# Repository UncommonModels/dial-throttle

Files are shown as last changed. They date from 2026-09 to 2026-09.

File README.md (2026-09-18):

# Dial Throttle (M5Stack Dial + SparkFun Qwiic Numpad)



This project turns an `M5Stack Dial` into a handheld model railroad throttle. It talks to JMRI
over WiThrottle, or joins an LCC network directly, with a `SparkFun Qwiic Keypad/Numpad
(COM-15290)` for function, turnout and loco-select keys.

**Documentation: <https://ngpaladi.github.io/dial-throttle/>**

| Idle, no loco | Half-step between notches | Ramping to notch 5 | Full speed |
| --- | --- | --- | --- |
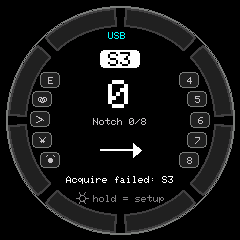
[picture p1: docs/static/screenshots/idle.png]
idle
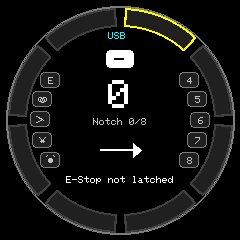
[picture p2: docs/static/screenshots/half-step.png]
half step
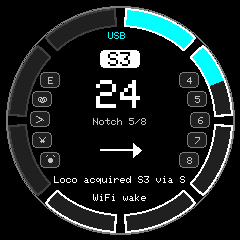
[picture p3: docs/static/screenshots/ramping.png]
ramping
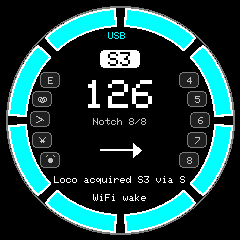
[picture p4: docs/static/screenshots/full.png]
full
|  |  |  |  |

| Reverse | E-Stop latched | Battery gauge | Settings menu |
| --- | --- | --- | --- |
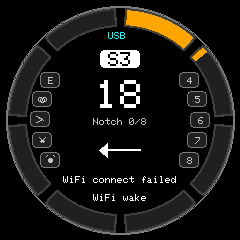
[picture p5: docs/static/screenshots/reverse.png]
reverse
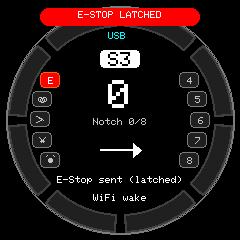
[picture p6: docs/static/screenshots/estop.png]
estop
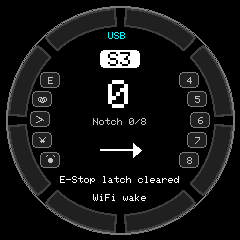
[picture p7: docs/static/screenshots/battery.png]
battery
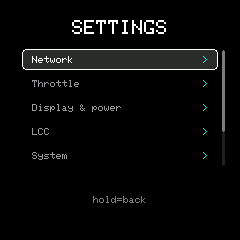
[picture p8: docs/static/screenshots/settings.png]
settings
|  |  |  |  |

## Features

- Notched throttle with momentum on the dial: 4, 8, 12 or 16 notches over speed steps `0..126`.
- Touchscreen brake, dial-button stop and direction change, and a latched emergency stop.
- WiThrottle for JMRI, or LCC / OpenLCB over GridConnect as a real node.
- Keypad functions, turnouts and loco selection, plus RFID loco selection with an optional
  MySQL lookup.
- WiFi, server and throttle settings stored in flash and editable on the device.
- Idle power saving for battery use that never cuts the link while the train is moving.

## Parts

| Qty | Part | Description |
| --- | --- | --- |
| 1 | `K130-V11` | M5Stack Dial |
| 1 | `15290` | SparkFun Qwiic Keypad, 12 button |
| 1 | `15109` | Qwiic to I2C Grove cable, 150 mm |
| 1 | `LION-1865-34` | 18650 Li-ion cell, 3.7 V 3.4 Ah |
| 1 | `BH-18650-PC` | 18650 holder, PC pin |
| 1 | `3922` | Molex Pico Blade 2-pin cable |
| 1 | `FE-USB2CC-PM-6IN` | Panel-mount USB-C cable, 6 in |

`parts/partslist.csv` has the Digi-Key numbers, and the
[Parts page](https://ngpaladi.github.io/dial-throttle/docs/parts/) explains what each item is for
and what the optional additions are.

## Quick start

With [arduino-cli](https://arduino.github.io/arduino-cli/) and `make`:

```bash
make flash PORT=/dev/ttyACM0   # build and upload; the first build downloads the ESP32 core
make monitor                   # serial console at 115200 baud
make help                      # every target
```

Or run the guided installer, which fetches arduino-cli for you: `./install.sh` on Linux and
macOS, `.\install.ps1` or `install.bat` on Windows.

To use the Arduino IDE, open `DialThrottle/DialThrottle.ino` and follow the board settings in
[Getting started](https://ngpaladi.github.io/dial-throttle/getting-started/#build-with-the-arduino-ide).

A unit with nothing saved opens its settings menu on first boot, so WiFi and the server can be
set on the device. Compile-time defaults are in `DialThrottle/config.h`.

## Repository layout

| Path | Contents |
| --- | --- |
| `DialThrottle/` | Arduino sketch: firmware, `config.h`, and `sketch.yaml` with pinned versions |
| `Makefile` | Build, flash, monitor and docs targets |
| `install.py` | Guided installer (`install.sh`, `install.ps1` and `install.bat` wrap it) |
| `docs/` | Hugo documentation site |
| `parts/partslist.csv` | Parts list, rendered on the site's Parts page |
| `tools/screenshot.py` | Captures the screen over serial |
| `case/` | Printable case |
| `rfid_mysql_schema.sql` | Sample table for RFID lookups |

## Documentation site

The site in `docs/` is built with [Hugo](https://gohugo.io/) and published to GitHub Pages by
`.github/workflows/pages.yml` on every push that touches `docs/` or `parts/`.

```bash
make serve                     # dev server with live reload on :1313
make docs                      # build into docs/public
```

The Parts page is generated from `parts/partslist.csv`, so editing that CSV updates the
documentation. `make site-assets` restages it, and `make docs` and `make serve` do that for you.

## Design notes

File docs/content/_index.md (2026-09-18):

---
title: "Dial Throttle"
---
| Idle, no loco | Half-step between notches | Ramping to notch 5 | Full speed |
| --- | --- | --- | --- |
| {{< shot idle.png "idle" >}} | {{< shot half-step.png "half step" >}} | {{< shot ramping.png "ramping" >}} | {{< shot full.png "full" >}} |

| Reverse | E-Stop latched | Battery gauge | Settings menu |
| --- | --- | --- | --- |
| {{< shot reverse.png "reverse" >}} | {{< shot estop.png "estop" >}} | {{< shot battery.png "battery" >}} | {{< shot settings.png "settings" >}} |

## What it does

- Connects to your WiFi network and to a JMRI WiThrottle server (default port `12090`), or to an
  LCC GridConnect server as a real OpenLCB node.
- Uses the dial as a notched throttle with momentum. You choose 4, 8, 12 or 16 notches, and speed
  runs over steps `0..126`.
- Caps reverse at half the notches by default, so the dial only reaches half speed backwards.
- Brakes while you hold the touchscreen. A press of the dial button stops the loco, or reverses it
  when already stopped.
- Adds function, turnout and loco-select keys through a SparkFun Qwiic keypad.
- Selects a loco by RFID tag, looked up in a MySQL table, a local map, or the tag UID itself.
- Saves power on battery by dimming, turning the display off, suspending WiFi and finally
  powering off, but never while the train is moving.
- Keeps WiFi, server and throttle settings in flash, editable on the device.

## Where to go next

| Page | Covers |
| --- | --- |
| [Getting started]({{< relref "docs/getting-started" >}}) | Hardware, wiring, building and flashing |
| [Parts list]({{< relref "docs/parts" >}}) | What to order, with Digi-Key numbers |
| [Using the throttle]({{< relref "docs/using" >}}) | Dial controls, keypad, settings menu |
| [Protocols]({{< relref "docs/protocols" >}}) | WiThrottle and LCC details |
| [Power and battery]({{< relref "docs/power" >}}) | Idle tiers, battery gauge and charge detection |
| [RFID]({{< relref "docs/rfid" >}}) | Tag lookup and the MySQL table |
| [Serial console]({{< relref "docs/serial" >}}) | Debug commands and screenshots |
| [Troubleshooting]({{< relref "docs/troubleshooting" >}}) | JMRI setup and common problems |

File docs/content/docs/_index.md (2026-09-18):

---
title: "Documentation"
---

Building, configuring and operating the Dial Throttle.

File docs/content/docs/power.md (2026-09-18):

---
title: "Power and battery"
description: "Idle power saving, the battery gauge and charge detection."
weight: 5
---

## Idle tiers

The firmware saves power in stages as the throttle sits idle.

| Tier | After | What happens |
| --- | --- | --- |
| Active | Any input | Backlight at full brightness, WiFi in minimum modem sleep |
| Dim | Dim delay | Backlight dimmed, WiFi in maximum modem sleep, RFID and keypad polled less often |
| Display off | Display-off delay | Backlight off and the LCD panel asleep. Once the loco is stopped, WiFi turns off and the ESP32 light-sleeps between polls |
| Power off | Power-off minutes, loco stopped | The loco is released, the session closed, and the unit powers down |

Any input returns to the active tier: the dial, touch, the button, the keypad, an RFID tag or a
serial command. During light sleep the unit wakes on dial rotation, the dial button, a screen
touch, or every `LIGHT_SLEEP_INTERVAL_MS`.

After a power off on battery, press the dial button to turn the unit back on. On USB power it
deep-sleeps instead, and a screen touch reboots it. The backlight pin is held low through deep
sleep, so the screen stays dark.

> WiFi is never suspended, and the unit never light-sleeps or powers off, while the loco is
> moving or braking. A train running hands-off keeps receiving heartbeats.

### Other savings

- The RFID reader's 13.56 MHz field is only on for a few milliseconds per poll
  (`RFID_POLL_ACTIVE_MS`, `RFID_POLL_IDLE_MS`).
- The keypad is polled on a schedule (`KEYPAD_POLL_ACTIVE_MS`, `KEYPAD_POLL_IDLE_MS`). It buffers
  presses in its own FIFO between polls.
- WiFi reconnects don't block, and WiThrottle reconnects are retried every 5 seconds.

### USB serial and light sleep

USB serial drops during light sleep. By default light sleep is skipped while a computer is
attached (`LIGHT_SLEEP_SKIP_WHEN_USB_SERIAL`). It still happens on battery or a plain USB
charger. If you plug a light-sleeping unit into a computer and the port doesn't appear, touch the
screen or turn the dial first; it stays awake while the computer is attached.

### Tuning

Brightness, delays and the power-off time are in the settings menu. The rest are in `config.h`:

- `ENABLE_WIFI_MODEM_SLEEP`, `ENABLE_WIFI_MAX_MODEM_SLEEP_WHEN_IDLE`
- `ENABLE_WIFI_POWER_GATING_WHEN_DISPLAY_OFF`
- `ENABLE_DISPLAY_PANEL_SLEEP`
- `ENABLE_LIGHT_SLEEP_WHEN_DISPLAY_OFF`, `LIGHT_SLEEP_INTERVAL_MS`, `LIGHT_SLEEP_SKIP_WHEN_USB_SERIAL`
- `ENABLE_RFID_ANTENNA_DUTY_CYCLE`, `RFID_POLL_ACTIVE_MS`, `RFID_POLL_IDLE_MS`
- `KEYPAD_POLL_ACTIVE_MS`, `KEYPAD_POLL_IDLE_MS`
- `UI_MIN_REDRAW_INTERVAL_MS`, which merges bursts of changes into one frame
- `CPU_FREQ_MHZ`, 240 by default. A full redraw takes about 17 ms of CPU at 240 MHz and about
  104 ms at 80 MHz. Inputs are polled between frames, so a slow redraw makes the dial feel laggy.
  Drop to 80 only if you'd rather have the battery life than the responsiveness.

## Battery gauge

| Battery gauge | Low battery |
| --- | --- |
| {{< shot battery.png "battery" >}} | {{< shot battery-low.png "low" >}} |

The Dial has a 1.25 mm 2-pin battery connector and a charger, but no battery voltage sense line,
so a stock unit cannot read its battery. To show the battery level, add a resistor divider from
the battery to an ADC1 pin on Port B:

```
BAT+ ---[ R1 100k ]---+--- GPIO1 (or GPIO2, Port B)
                      |
                   [ R2 100k ]
                      |
                     GND
```

Then in `config.h` set `BATTERY_ADC_PIN` to `1` (or `2`) and `BATTERY_DIVIDER_RATIO` to
`(R1 + R2) / R2`, which is 2.0 for 100k/100k.

A battery icon with the percentage appears at the top of the screen. It turns yellow below 40%
and red at or below `BATTERY_LOW_WARN_PERCENT`, with a one-time low-battery beep. Set
`BATTERY_SHOW_VOLTAGE` to `true` to show millivolts while calibrating the ratio. With
`BATTERY_ADC_PIN = -1` the indicator is hidden.

## Charging and power source

According to the Dial schematic, the TP4057 charger's `CHRG` and `STDBY` pins aren't wired to the
ESP32, and the Grove 5V pin is boosted from the battery. A stock unit can't tell whether it is
charging.

Without extra hardware it can only detect a USB *host*, meaning a computer sending USB frames. A
plain USB charger or the DC terminal looks the same as battery power. The indicator row above the
loco address shows:

| Label | Meaning | Needs |
| --- | --- | --- |
| `USB` | A computer is attached | Nothing |
| `PWR` | External power detected | `POWER_SENSE_ADC_PIN` |
| `CHG` | Charging | `CHARGE_STATUS_PIN` |

- **`POWER_SENSE_ADC_PIN`**: wire a 100k/100k divider from the 5V input rail (StampS3 header pin
  `M5V`, net `+5VIN`, only live on USB or DC-terminal power) to GPIO1 or GPIO2. Don't use the
  Grove 5V pin; it is powered on battery too.
- **`CHARGE_STATUS_PIN`**: solder a wire from the TP4057 `CHRG` pin (pin 1, open drain, low while
  charging) to a free GPIO: GPIO39, 43 or 44 on the StampS3 header, or GPIO1 or 2. The firmware
  enables the internal pull-up.

With `POWER_OFF_ONLY_ON_BATTERY` (on by default) the idle power-off is skipped whenever external
power is detected. On a stock unit that only covers a computer, so on a wall charger it still
powers off after the idle time. The `bat` serial command prints the detected source and charge
state.

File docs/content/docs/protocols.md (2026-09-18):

---
title: "Protocols"
description: "WiThrottle for JMRI, or LCC/OpenLCB over GridConnect."
weight: 4
---

The throttle speaks one of two protocols. Choose it on the device under **Network**, or set the
default for an unconfigured unit with `THROTTLE_PROTOCOL_DEFAULT` in `config.h`.

## WiThrottle

WiThrottle is the default. The implementation was checked against the JMRI WiThrottle protocol
specification and JMRI's own server code.

### Commands sent

| Command | Purpose |
| --- | --- |
| `N` | Client name |
| `HU` | Unique client ID |
| `*+`, then `*` every 2 seconds | Heartbeat |
| `M0+` | Acquire the loco |
| `M0A...<;>V` | Speed |
| `M0A...<;>R` | Direction |
| `M0A...<;>f` | Set a function's state |
| `M0A...<;>X` | Emergency stop |

Functions use the force-function form, which sets a function's state directly instead of
emulating a key press. It needs WiThrottle protocol 2.0 or later.

### Messages handled

The receive path handles the version line, alerts and info messages, acquire confirmations,
steal prompts, releases, and property notifications for speed, direction and function state.
Reports for other locomotives on the throttle are ignored.

A negative speed from the server means the command station has the address in emergency stop.
That latches the throttle's own E-Stop, so momentum cannot ramp the train back up.

### Acquiring

Acquiring is confirmed, not assumed. If the server doesn't answer, the request is retried up to
`ACQUIRE_MAX_ATTEMPTS` times. If another throttle holds the loco, the server asks whether to
steal it. `WITHROTTLE_AUTO_STEAL` decides whether that happens automatically or waits for the
`steal` serial command.

Once the loco is confirmed, the throttle pushes its current direction, speed and function states
to the server. That is what restores the train after a reconnect.

## LCC / OpenLCB over GridConnect

Choose **LCC** under **Network** in the settings menu, or build with:

```bash
make flash DEFINES=-DTHROTTLE_PROTOCOL_DEFAULT=PROTOCOL_LCC_GRIDCONNECT
```

The throttle opens a GridConnect TCP connection to the configured server, either JMRI's LCC
GridConnect server or a CAN gateway, and joins the network as a real node:

- Allocates a CAN alias with the standard CID, RID and AMD sequence, and reclaims on a conflict.
- Announces itself with Initialization Complete, and answers Verify Node ID and Alias Map
  Enquiry.
- Finds the locomotive by its well-known DCC train node ID, `06.01.00.00.xx.xx`, where long
  addresses set the top two bits. Short address 3 is `06.01.00.00.00.03`; long address 341 is
  `06.01.00.00.C1.55`.
- Assigns itself as that train's controller, then sends speed, functions and emergency stop with
  the traction protocol. Speed is an IEEE half-precision value in metres per second whose sign
  carries direction, so reverse at a standstill is negative zero.

### Node ID

Set `LCC_NODE_ID` for this throttle. The default keeps the `05.01.01` prefix, which openlcb.org
set aside for non-commercial use, and fills the low three bytes from the board's MAC address, so
each unit is unique.

### Check against your layout

- **Speed scale.** `LCC_FULL_SPEED_MPH` maps the top notch onto a prototype speed. The default of
  126 makes one speed step one mph, which matches the usual OpenMRN command station mapping.
- **Turnouts.** LCC has no address-based turnout command, so turnout `n` produces event
  `LCC_TURNOUT_EVENT_BASE + 2n` or `+ 2n + 1`. That is a convention, not a standard.

## Testing without a layout

Build with serial-only output to inspect either protocol:

```bash
make flash DEFINES=-DSERIAL_OUTPUT_ONLY_DEFAULT=1
```

Every frame the throttle would send is printed to the console instead. The serial commands
`wtin <line>` and `lccin <frame>` feed in messages as if a server had sent them, and `lcc` prints
the node ID, alias and controller state.

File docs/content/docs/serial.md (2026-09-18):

---
title: "Serial console"
description: "Debug commands and screen captures over USB."
weight: 7
---

The throttle takes commands over USB serial at 115200 baud. Type a command and press Enter.

```bash
make monitor                   # or: make monitor PORT=/dev/ttyACM1
```

## Throttle and loco

| Command | Action |
| --- | --- |
| `status` | Print WiFi, server and loco state |
| `acq` | Acquire the configured loco |
| `rel` | Release the loco |
| `loco <addr> <s/l>` | Set the active loco, short or long, and acquire it |
| `steal` | Take a loco another throttle holds |
| `speed <0-126>` | Set the speed step |
| `notch <n>` | Set the throttle notch, from 0 to the notch count |
| `dir <f/r/t>` | Forward, reverse or toggle |
| `fn <0-28> <on/off/t>` | Function on, off or toggle |
| `estop` | Emergency stop |
| `clear` | Clear the E-Stop latch (`estop clear` also works) |

## Connection

| Command | Action |
| --- | --- |
| `wifi` | Reconnect WiFi |
| `wt` | Reconnect to the server |
| `send <raw>` | Send a raw WiThrottle line, e.g. `send M0A*<;>qV` |
| `lcc` | LCC node ID, alias and controller state |

## Settings

| Command | Action |
| --- | --- |
| `settings` | Print the settings and open the settings menu |
| `set ssid <name>` | Set and save the WiFi name |
| `set pass <password>` | Set and save the WiFi password |
| `set ip <a.b.c.d>` | Set and save the server address |
| `set port <n>` | Set and save the server port |
| `set proto <wt/lcc>` | Choose WiThrottle or LCC GridConnect |
| `defaults` | Reset every setting to the `config.h` defaults |

## Power and diagnostics

| Command | Action |
| --- | --- |
| `diag` | Idle timer, last input source, encoder count, notch and pending half-step, redraw and loop timing. Doesn't reset the idle timer |
| `bat` | Battery reading, power source and charge state |
| `tier <0/1/2>` | Force a backlight tier. `tier 2` checks that the screen really goes dark |
| `off` | Power off now |
| `help` | List every command |

## Testing

| Command | Action |
| --- | --- |
| `enc <counts>` | Inject raw encoder counts, 2 per detent |
| `btn [long]` | Fake a dial button press, or a long press |
| `simbat <pct/-1>` | Fake a battery percentage; `-1` clears it |
| `wtin <line>` | Inject a line as if the WiThrottle server sent it |
| `lccin <frame>` | Inject a GridConnect frame |
| `shot` | Dump the screen as hex |

To see what the throttle would send without a layout, build with
`make flash DEFINES=-DSERIAL_OUTPUT_ONLY_DEFAULT=1`. Outgoing WiThrottle lines are printed as
`WT> ...` instead of being transmitted.

## Screenshots

`tools/screenshot.py` sends `shot`, decodes the frame and writes a PNG. It needs `pyserial` and
`Pillow`. Every screenshot on this site was captured this way.

```bash
make screenshot PORT=/dev/ttyACM0
python3 tools/screenshot.py --setup "notch 5" --settle 3 shot.png
```

`--setup` runs a serial command before the capture and can be repeated. `--settle` waits that many
seconds afterwards, which lets momentum ramp the speed up. Without Pillow the raw hex dump is saved
next to the output, and `--decode dump.hex out.png` converts it later.

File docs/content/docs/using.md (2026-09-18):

---
title: "Using the throttle"
description: "Dial controls, the keypad, and the on-device settings menu."
weight: 3
---

## Dial controls

The throttle works like a locomotive notch controller with momentum.

| Control | Action |
| --- | --- |
| Turn the dial | Select a throttle notch |
| Hold the touchscreen | Brake while held |
| Press the dial button, moving | Stop immediately: notch 0, speed 0 |
| Press the dial button, stopped | Reverse direction |
| Press the dial button, E-Stop latched | Clear the latch |
| Hold the dial button about a second | Open the settings menu |

### Notches

Two detents in the same direction move one notch, like a gated notch lever: one detent up then
one back down returns to the notch and changes nothing. A half-step shows as a yellow outline on
the block being moved into, and is held until you complete or undo it. The detents per notch can
be changed in the settings menu.

| Half-step | 4 notches | 16 notches |
| --- | --- | --- |
| {{< shot half-step.png "half step" >}} | {{< shot notches-4.png "4 notches" >}} | {{< shot notches-16.png "16 notches" >}} |

A block is outlined white when its notch is selected, and fills with the direction color as the
actual speed reaches it. The big number is the real speed step (`0..126`) and the small line
under it is the notch. The address shows `-` until a loco is selected.

Reverse is capped at half the notches, so the dial only reaches half speed backwards. Set
`REVERSE_NOTCH_DIVISOR` in `config.h` to 1 to give reverse the full range.

### Momentum and braking

Actual speed ramps toward the selected notch at `MOMENTUM_ACCEL_STEPS_PER_SEC` (default 8 per
second, about 16 seconds from stop to full) and coasts down at `MOMENTUM_DECEL_STEPS_PER_SEC`
(default 5 per second). Both rates can be changed in the settings menu, and momentum can be
turned off there for direct notch-to-speed control.

Holding the touchscreen brakes hard. On release the ramp resumes toward the selected notch.
Braking to a full stop drops the notch to 0.

### Encoder decoding

The raw encoder count must move a full detent before anything is accepted, so contact chatter
never registers. A reversal within `ENCODER_REVERSAL_PAUSE_MS` of a detent is treated as a decoder
miscount and absorbed. A deliberate turn-back after a pause registers immediately.

## Keypad

With a SparkFun Qwiic keypad attached:

| Key | Action |
| --- | --- |
| `0` to `8` | Toggle function `F0` to `F8` |
| `9` | Emergency stop |
| `*` | Turnout mode: enter digits, press `*` again to flip |
| `#` | Loco select mode: enter digits, press `#` again to acquire |

Selecting a new loco releases the old one and acquires the new one. Speed, direction, function
and E-Stop actions acquire the loco first if needed.

## Settings menu

Hold the dial button for about a second to open the menu. The home screen shows
`Btn Hold = Setup` as a reminder. The menu only opens with the train stopped.

| Menu | Throttle page | Server address | Text entry |
| --- | --- | --- | --- |
| {{< shot settings.png "settings" >}} | {{< shot settings-throttle.png "throttle page" >}} | {{< shot settings-ip.png "ip" >}} | {{< shot settings-text.png "text entry" >}} |

Turn the dial to move or to change a value, press to activate or to step to the next field, and
hold to go back. On the keypad, digits type straight into the field, `#` acts as a press and `*`
as a hold.

| Page | Settings |
| --- | --- |
| Network | WiFi name and password, protocol (WiThrottle or LCC), server address, port |
| Throttle | Default loco address and type, notches (4, 8, 12, 16), detents per notch, reverse dial direction, momentum, acceleration and deceleration |
| Display & power | Active and dim brightness, dim and display-off delays, power-off minutes (0 means never), sound |
| System | RFID reader on or off, reset to defaults |

Switching protocol moves the port to that protocol's usual default. The server address is edited
octet by octet. Text fields use a character picker: turn to a character and press to add it, `<X`
backspaces, and `OK` or a hold finishes. The password is shown masked.

Choose **Save & exit** to write the settings and reconnect, or **Discard & exit** to reload what
was last saved. Settings are stored in flash as one versioned record and survive a reflash.
Firmware whose settings layout has changed falls back to defaults rather than loading a
mismatched record.

The same values can be set over the [serial console]({{< relref "docs/serial" >}}).

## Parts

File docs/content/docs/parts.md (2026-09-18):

---
title: "Parts list"
description: "Everything needed to build one throttle."
weight: 2
---

One throttle, as built. Every line is stocked at Digi-Key, and the quantities are per unit.

{{< parts >}}

## What each part is for

- **M5Dial** is the whole throttle: an ESP32-S3, a round 240×240 touchscreen, a rotary encoder
  with a push button, an RFID reader and a speaker in one enclosure.
- **Qwiic keypad and cable** add the function, turnout and loco-select keys. The throttle works
  without them, and picks one up whenever it is plugged in.
- **18650 cell, holder and Pico Blade cable** make it cordless. The Dial charges the cell over
  USB-C. The cable matches the Dial's 1.25 mm 2-pin battery connector, so check the polarity
  against the case before the first connection.
- **Panel-mount USB-C cable** brings the Dial's USB port out to the edge of the case, for
  charging and reflashing without opening it.

A printable case is in `case/` in the repository, as an STL with the FreeCAD source beside it. It is designed so all parts mount with  M2 screws without threaded inserts.

## Optional extras

None of these are in the list above; all are described elsewhere in these docs.

| Add | For | See |
| --- | --- | --- |
| Two 100 kΩ resistors | Battery voltage divider, which the gauge needs | [Battery gauge]({{< relref "docs/power#battery-gauge" >}}) |
| Two more 100 kΩ resistors | Sensing external power on the 5 V input rail | [Charging and power source]({{< relref "docs/power#charging-and-power-source" >}}) |
| One wire to the charger's `CHRG` pin | Showing charge state | [Charging and power source]({{< relref "docs/power#charging-and-power-source" >}}) |
| RFID tags, 13.56 MHz | Selecting a loco by tag | [RFID]({{< relref "docs/rfid" >}}) |

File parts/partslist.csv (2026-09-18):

Digikey Part Number | Manufacturer Part Number | Description | Quantity
2221-K130-V11-ND | K130-V11 | M5DIAL V1.1 | 1
1568-15290-ND | 15290 | QWIIC KEYPAD - 12 BUTTON | 1
1568-15109-ND | 15109 | QWIIC TO I2C GROVE CABLE 150MM | 1
3145-LION-1865-34-ND | LION-1865-34 | BATTERY LITH-ION 3.7V 3.4AH 1865 | 1
BH-18650-PC-ND | BH-18650-PC | BATTERY HOLDER 18650 PC PIN | 1
1528-2732-ND | 3922 | MOLEX PICO BLADE 2-PIN CABLE - 2 | 1
5600-FE-USB2CC-PM-6IN-ND | FE-USB2CC-PM-6IN | 6inch USB2-C to C Panel M/F | 1

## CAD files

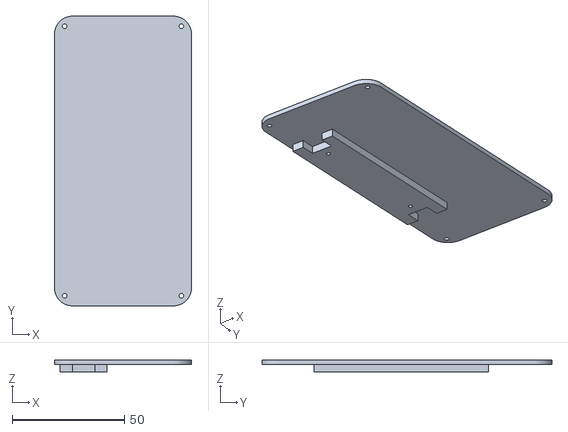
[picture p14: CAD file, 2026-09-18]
case/M5DialController-Backplate.stl
61.0 x 129.0 x 5.30

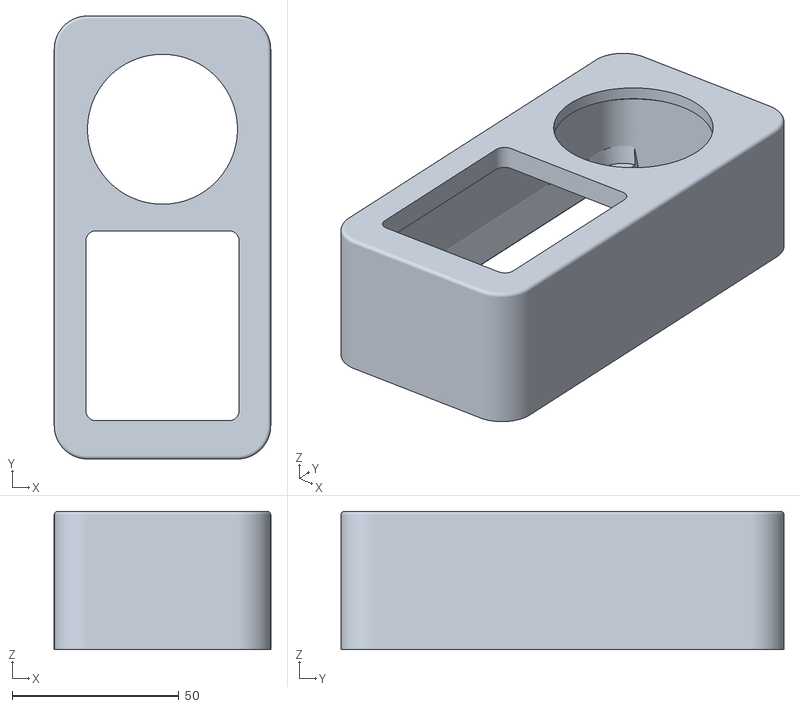
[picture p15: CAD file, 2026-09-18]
case/M5DialController-Body.stl
65.0 x 133.0 x 41.5

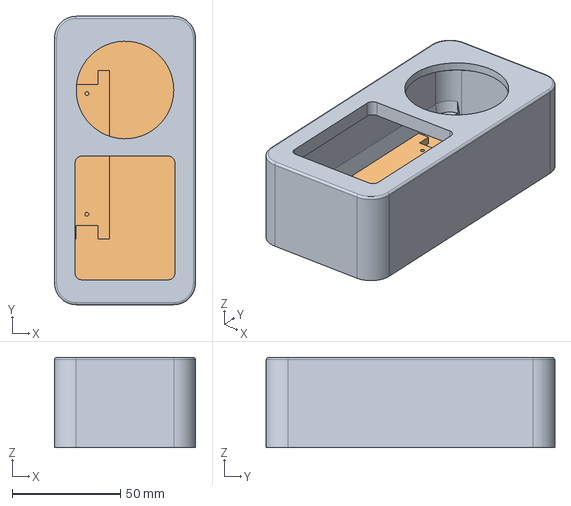
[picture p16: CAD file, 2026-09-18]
case/M5DialController.FCStd
65.0 x 133.0 x 41.5 mm
Backplate

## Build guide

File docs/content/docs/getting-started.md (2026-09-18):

---
title: "Getting started"
description: "Hardware, wiring, and building and flashing the firmware."
weight: 1
---

## Hardware

- M5Stack Dial (ESP32-S3)
- SparkFun Qwiic Keypad/Numpad (COM-15290), optional
- Qwiic cable

The [parts list]({{< relref "docs/parts" >}}) has the exact items, with Digi-Key numbers. A
printable case is in the repository under `case/` (`M5DialController.stl`, with the FreeCAD
source alongside).

## Wiring

The Qwiic connector carries `3V3`, `GND`, `SDA` and `SCL`. Plug the Qwiic cable into the Dial's
Grove port (Port A), or into an adapter that exposes `3V3/GND/SDA/SCL`.

The firmware expects the keypad at the SparkFun default I2C address, `0x4B`. A keypad plugged in
after boot is picked up within about 10 seconds.

### Battery
The M5Stack Dial has a Molex Picoblade 1.25mm pitch connector under the Stamp module on the bottom of the dial. The parts list suggests a preassembled cable to break this out into wire leads. **BE EXTREMELY CAREFUL ABOUT POLARITY**. The PCB should have an indicator of the positive terminal. This may not be the red cable in a red/black pair for an assembled cable. If you choose not to use the 18650 battery setup (which requires soldering of the leads to the battery holder), you likely can find a smaller battery and shrink the height of the case. However, this will likely require constructing a custom adapter cable.

## Project layout

| Path | Contents |
| --- | --- |
| `DialThrottle/` | The Arduino sketch. `setup()` and `loop()` are in `main.cpp` |
| `DialThrottle/config.h` | Compile-time defaults and hardware options |
| `DialThrottle/sketch.yaml` | Board options and pinned core and library versions |
| `Makefile` | Build, flash, monitor and docs targets |
| `install.py` | Guided installer for people who don't want to use a terminal much |
| `parts/partslist.csv` | The [parts list]({{< relref "docs/parts" >}}), rendered onto this site |
| `docs/` | This documentation site (Hugo) |
| `tools/screenshot.py` | Captures the screen over serial |
| `rfid_mysql_schema.sql` | Sample table for RFID lookups |

## Configure

WiFi, the server address, the protocol and the default loco can all be set on the device after
flashing (see [Using the throttle]({{< relref "docs/using#settings-menu" >}})). A unit with
nothing saved opens the settings menu on first boot.

To bake in defaults instead, edit `DialThrottle/config.h` before building:

- `WIFI_SSID`, `WIFI_PASS`
- `WITHROTTLE_HOST`, `WITHROTTLE_PORT`
- `LOCO_ADDRESS`, `LOCO_IS_LONG_ADDRESS`
- `THROTTLE_PROTOCOL_DEFAULT`, see [Protocols]({{< relref "docs/protocols" >}})

Settings saved on the device take priority over these values, and survive a reflash.

## Build and flash with make

You need [arduino-cli](https://arduino.github.io/arduino-cli/) and `make`. The board, the ESP32
core and every library are pinned in `DialThrottle/sketch.yaml`, so the first build downloads
what it needs. The ESP32 core alone is several hundred MB.

```bash
make build                     # compile
make flash                     # compile and upload to /dev/ttyACM0
make monitor                   # serial console at 115200 baud
make help                      # list every target
```

With more than one board attached, pass the port:

```bash
make flash PORT=/dev/serial/by-id/usb-Espressif_USB_JTAG_serial_debug_unit_<MAC>-if00
```

`DEFINES` adds preprocessor flags without editing `config.h`. Changing it forces a rebuild:

```bash
make flash DEFINES=-DTHROTTLE_PROTOCOL_DEFAULT=PROTOCOL_LCC_GRIDCONNECT
```

## Build with the Arduino IDE

1. Install the ESP32 boards package. Add
   `https://raw.githubusercontent.com/espressif/arduino-esp32/gh-pages/package_esp32_index.json`
   under **File > Preferences > Additional boards manager URLs**, then install **esp32** by
   Espressif, version 3.1.3, from the Boards Manager.
2. Install these libraries from the Library Manager: **M5Dial**, **M5Unified**, **M5GFX**,
   **SparkFun Qwiic Keypad Arduino Library** and **MySQL Connector Arduino**. Running
   `make deps` does both steps from a terminal, at the pinned versions.
3. Open `DialThrottle/DialThrottle.ino`.
4. Under **Tools**, choose board **M5Dial** and set:
   - USB CDC On Boot: **Enabled**
   - USB Mode: **Hardware CDC and JTAG**
   - Flash Size: **8MB (64Mb)**
   - Partition Scheme: **8M with spiffs (3MB APP/1.5MB SPIFFS)**
5. Select the port and click **Upload**.

> USB CDC On Boot must be enabled, or the serial console goes to pins that the Dial doesn't
> expose.

## Guided installer

For less technical users, the installer downloads arduino-cli if needed, offers to open
`config.h`, lets you pick the serial port, then builds and flashes.

| Platform | Command |
| --- | --- |
| Linux, macOS | `./install.sh` |
| Windows PowerShell | `.\install.ps1` |
| Windows Command Prompt | `install.bat` |

All three need Python 3. For unattended installs at clubs or events:

```bash
./install.sh --yes --port /dev/ttyACM0 --no-monitor
```

| Flag | Effect |
| --- | --- |
| `--yes`, `-y` | Accept defaults, never prompt |
| `--port <path>` | Use this port without asking |
| `--monitor`, `--no-monitor` | Open, or skip, the serial monitor after flashing |
| `--edit-config`, `--no-edit-config` | Open, or skip, the config editor |
| `--help` | Show all options |

## Serial permissions on Linux

If the board doesn't show up or the upload is refused, add yourself to the `dialout` group, then
log out and back in:

```bash
sudo usermod -aG dialout "$USER"
```

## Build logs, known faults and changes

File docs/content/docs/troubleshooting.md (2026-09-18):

---
title: "Troubleshooting"
description: "JMRI setup and the problems that come up most."
weight: 8
---

## JMRI setup

1. In JMRI, start the WiThrottle server.
2. Confirm the server port, `12090` by default.
3. Make sure the Dial and the JMRI computer are on the same network.
4. If a firewall is enabled, allow TCP port `12090`.

## Keypad not detected

- Check the Qwiic cable and the connector.
- Confirm the keypad address is `0x4B`, the SparkFun default.
- The status line shows `Qwiic keypad NOT found` at boot. A keypad plugged in later is detected
  within about 10 seconds.

## Can't connect to WiThrottle

- Check the server address and port under **Network** in the settings menu, or with `settings`
  on the serial console.
- Make sure the JMRI WiThrottle server is running.
- `status` on the serial console shows the WiFi and server state.

## Loco doesn't respond

- Check the loco address and whether it is a short or long address.
- If another throttle holds the loco, send `steal`, or set `WITHROTTLE_AUTO_STEAL`.
- If E-Stop is latched, press the dial button to clear it.

## Board doesn't appear, or the upload fails

- On Linux, add yourself to the `dialout` group, then log out and back in:
  `sudo usermod -aG dialout "$USER"`.
- A light-sleeping unit may not show up when plugged into a computer. Touch the screen or turn the
  dial first.
- With more than one ESP32 attached, `/dev/ttyACM0` may be the wrong board. Pass the stable name:
  `make flash PORT=/dev/serial/by-id/usb-Espressif_USB_JTAG_serial_debug_unit_<MAC>-if00`.
- In the Arduino IDE, check that USB CDC On Boot is enabled. Otherwise the console is silent.

## Screen stays lit while powered off

Older firmware didn't hold the backlight pin low in deep sleep, so on a
wall charger the screen could stay lit after an idle power-off. Update to the current firmware.

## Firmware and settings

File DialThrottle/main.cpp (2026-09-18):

#include <Arduino.h>
#include <MySQL_Connection.h>
#include <MySQL_Cursor.h>
#include <math.h>
#include <M5Dial.h>
#include <WiFi.h>
#include <Wire.h>
#include <SparkFun_Qwiic_Keypad_Arduino_Library.h>
#include <HWCDC.h>
#include <driver/gpio.h>
#include <driver/rtc_io.h>
#include <esp_sleep.h>
#include <esp_wifi.h>

#include "config.h"
#include "lcc.h"
#include "settings.h"

namespace {

WiFiClient wtClient;
KEYPAD keypad;
M5Canvas uiCanvas(&M5Dial.Display);
bool uiCanvasReady = false;

uint16_t activeLocoAddress = LOCO_ADDRESS;
bool activeLocoIsLong = LOCO_IS_LONG_ADDRESS;
bool settingsWereStored = false;
String locoId;
bool locoSelected = false;
bool locoAcquired = false;
bool directionForward = true;
int speed126 = 0;
int throttleDemandSpeed = 0;
int throttleNotch = 0;
unsigned long lastMomentumMs = 0;
unsigned long lastDetentMs = 0;
int32_t momentumAccumMilli = 0;
const char* lastActivitySource = "boot";
uint32_t activityCount = 0;
bool functionState[29] = {false};
bool encoderUpdatingSpeed = false;
bool brakeHoldActive = false;
bool brakeRecovering = false;
int brakeRecoveryTargetSpeed = 0;
unsigned long lastBrakeStepMs = 0;
unsigned long lastBrakeTouchMs = 0;
bool brakeStoppedToZero = false;
bool estopLatched = false;

bool keypadAddressMode = false;
String keypadAddressBuffer;
bool keypadTurnoutMode = false;
String keypadTurnoutBuffer;
String lastRfidUid;
unsigned long lastRfidMs = 0;

unsigned long lastHeartbeatMs = 0;
unsigned long lastServerActivityMs = 0;

// WiThrottle session state.
bool locoAcquirePending = false;      // M0+ sent, waiting for the server to confirm
unsigned long locoAcquireSentMs = 0;
uint8_t locoAcquireAttempts = 0;
bool stealPending = false;            // server asked whether to steal the loco
float serverProtocolVersion = 0.0f;
// Speeds we sent recently. JMRI echoes every speed command back, and during a momentum ramp those
// echoes lag behind; matching them exactly avoids mistaking our own echo for another throttle.
struct SentSpeed {
  int16_t value;
  unsigned long atMs;
};
SentSpeed sentSpeeds[64] = {};
uint8_t sentSpeedIdx = 0;

String statusLine = "Booting...";
String infoLine = "";
unsigned long infoLineSetMs = 0;
bool uiDirty = true;
unsigned long lastUserActivityMs = 0;
uint8_t backlightMode = 0; // 0=active, 1=dim, 2=off
bool wifiSuspendedForPower = false;
bool displayPanelAsleep = false;
int8_t wifiPowerSaveApplied = -1; // -1 unknown, 0 none, 1 min modem, 2 max modem
bool wifiConnecting = false;
unsigned long wifiConnectStartMs = 0;
unsigned long wifiNextRetryMs = 0;
unsigned long wtNextRetryMs = 0;
uint32_t wtRetryIntervalMs = 5000;
bool keypadPresent = false;
unsigned long lastKeypadPollMs = 0;
unsigned long lastRfidPollMs = 0;
unsigned long lastRfidSeenMs = 0;
int batteryPercent = -1; // -1 = no gauge available
enum class PowerSource : uint8_t { Unknown, Battery, External };
enum class ChargeState : uint8_t { Unknown, NotCharging, Charging };
PowerSource powerSource = PowerSource::Unknown;
ChargeState chargeState = ChargeState::Unknown;
bool usbHostPresent = false;
int powerSenseMillivolts = -1;
unsigned long lastPowerSourceSampleMs = 0;
int batteryMillivolts = -1;
unsigned long lastBatterySampleMs = 0;
bool batteryLowWarned = false;
bool buttonLongHandled = false;

bool encoderStateInitialized = false;
bool encoderResyncPending = false;
int32_t encoderDetentRef = 0;   // raw count at the last accepted detent
int32_t encoderLastRaw = 0;
unsigned long encoderLastMotionMs = 0;
int8_t lastDetentDir = 0;
int8_t encoderPendingDetents = 0; // net detents travelled since the current notch position
uint32_t lastDrawUsec = 0;
unsigned long lastDrawMs = 0;
uint32_t lastRenderUsec = 0;
uint32_t maxLoopUsec = 0;
uint32_t lastLoopUsec = 0;

void setStatus(const String& s);
void setInfo(const String& s);
void sendWt(const String& line);
void setSpeed(int newSpeed);
void clearEmergencyStopLatch();
void backendAcquire();
void backendRelease();
void backendSendSpeed(int step);
void backendSendDirection(bool forward);
void backendSendFunction(uint8_t fn, bool on);
void backendEStop();
void backendQuit();
bool backendConnected();
void resyncLocoStateToServer();
void setStatus(const String& s);
void ensureLocoAcquired();
void applyStopAction(const char* statusText);
void noteUserActivity(const char* source = "?");
void updatePowerState();
void suspendWiFiForPower();
void resumeWiFiFromPower();
void enterBacklightMode(uint8_t mode);
void applyWiFiPowerSave();
void powerOffDevice();
void sampleBattery(bool force);
void samplePowerSource(bool force);
void applyNotch(int notch, bool fromEncoder);
void renderUi(LovyanGFX& g);
bool usingLcc();
void applySettings();
int notchCount();
int maxNotch();
int encoderSign();
int notchToSpeed(int notch);
int speedToNotch(int speed);
void syncEncoderToSpeed();

// Full-frame off-screen buffer so each redraw is a single push instead of clear-then-draw.
void initUiCanvas() {
  const int16_t w = M5Dial.Display.width();
  const int16_t h = M5Dial.Display.height();
  uiCanvas.setColorDepth(16);
  uiCanvasReady = uiCanvas.createSprite(w, h) != nullptr;
  if (!uiCanvasReady) {
    uiCanvas.setColorDepth(8);
    uiCanvasReady = uiCanvas.createSprite(w, h) != nullptr;
  }
  Serial.printf("UI canvas: %s (%d-bit), free heap %u\n", uiCanvasReady ? "ok" : "unavailable, drawing direct",
                uiCanvasReady ? uiCanvas.getColorDepth() : 0, static_cast<unsigned>(ESP.getFreeHeap()));
}

// Dump the rendered frame over serial as hex rows (decode with tools/screenshot.py).
void dumpScreenshot() {
  if (!uiCanvasReady) {
    Serial.println("! screenshot needs the UI canvas");
    return;
  }
  if (settings::isOpen()) {
    settings::render(uiCanvas);
  } else {
    renderUi(uiCanvas);
  }
  const int w = uiCanvas.width();
  const int h = uiCanvas.height();
  const int bpp = uiCanvas.getColorDepth() / 8;
  const uint8_t* buf = static_cast<const uint8_t*>(uiCanvas.getBuffer());
  Serial.printf("SHOT BEGIN %d %d %d\n", w, h, bpp * 8);
  static const char* hex = "0123456789ABCDEF";
  char line[240 * 4 + 1];
  for (int y = 0; y < h; ++y) {
    const uint8_t* row = buf + static_cast<size_t>(y) * w * bpp;
    int n = 0;
    for (int i = 0; i < w * bpp && n < static_cast<int>(sizeof(line)) - 2; ++i) {
      line[n++] = hex[row[i] >> 4];
      line[n++] = hex[row[i] & 0x0F];
    }
    line[n] = 0;
    Serial.println(line);
    Serial.flush();
  }
  Serial.println("SHOT END");
}

bool onExternalPower();
void drawUi(bool force = false);
void beep();

void beep() {
  if (settings::cfg.sound) {
    M5Dial.Speaker.tone(1200, 140);
  }
}

void beepRfidAddressChange() {
  if (settings::cfg.sound) {
    M5Dial.Speaker.tone(1650, 140);
  }
}

void noteUserActivity(const char* source) {
  lastUserActivityMs = millis();
  lastActivitySource = source;
  ++activityCount;
  if (backlightMode != 0) {
    enterBacklightMode(0);
  }
}

// True when it is safe to drop the WiThrottle link or sleep: nothing is moving or braking.
bool throttleIsIdleSafe() {
  return speed126 == 0 && throttleDemandSpeed == 0 && !brakeHoldActive && !brakeRecovering;
}

void suspendWiFiForPower() {
  if (SERIAL_OUTPUT_ONLY || !ENABLE_WIFI_POWER_GATING_WHEN_DISPLAY_OFF || wifiSuspendedForPower) {
    return;
  }

  wtClient.stop();
  WiFi.disconnect(true, true);
  WiFi.mode(WIFI_OFF);
  wifiSuspendedForPower = true;
  wifiConnecting = false;
  wifiPowerSaveApplied = -1;
  Serial.println("Power: WiFi suspended (loco stopped)");
  setInfo("WiFi sleep");
}

void resumeWiFiFromPower() {
  if (SERIAL_OUTPUT_ONLY || !wifiSuspendedForPower) {
    return;
  }

  WiFi.mode(WIFI_STA);
  wifiSuspendedForPower = false;
  wifiNextRetryMs = 0; // reconnect on the next loop pass
  setInfo("WiFi wake");
}

// Modem sleep depth follows the backlight tier: minimum while in use, maximum while idle.
void applyWiFiPowerSave() {
  if (SERIAL_OUTPUT_ONLY || wifiSuspendedForPower || WiFi.status() != WL_CONNECTED) {
    return;
  }
  int8_t want = 0;
  if (ENABLE_WIFI_MODEM_SLEEP) {
    want = (ENABLE_WIFI_MAX_MODEM_SLEEP_WHEN_IDLE && backlightMode != 0) ? 2 : 1;
  }
  if (want == wifiPowerSaveApplied) {
    return;
  }
  wifiPowerSaveApplied = want;
  esp_wifi_set_ps(want == 2 ? WIFI_PS_MAX_MODEM : (want == 1 ? WIFI_PS_MIN_MODEM : WIFI_PS_NONE));
}

void sleepDisplayPanel() {
  if (!ENABLE_DISPLAY_PANEL_SLEEP || displayPanelAsleep) {
    return;
  }
  M5Dial.Display.sleep();
  M5Dial.Display.waitDisplay();
  displayPanelAsleep = true;
}

void wakeDisplayPanel() {
  if (!displayPanelAsleep) {
    return;
  }
  M5Dial.Display.wakeup(); // restores the cached brightness, which is 0 here; set explicitly by caller
  delay(130);              // GC9A01 needs >=120 ms after SLPOUT before it reliably accepts pixel data
  M5Dial.Display.startWrite();
  M5Dial.Display.writeCommand(0x29); // DISPON, in case the panel dropped it during sleep
  M5Dial.Display.endWrite();
  displayPanelAsleep = false;
}

void enterBacklightMode(uint8_t mode) {
  if (mode == backlightMode) {
    return;
  }
  backlightMode = mode;
  Serial.printf("Power: %s\n", mode == 0 ? "active" : (mode == 1 ? "display dim" : "display off"));
  if (mode == 0) {
    if (wifiSuspendedForPower) {
      resumeWiFiFromPower();
    }
    wakeDisplayPanel();
    uiDirty = true;
    drawUi(true); // paint the frame before the backlight comes on
    M5Dial.Display.setBrightness(settings::cfg.brightnessActive);
  } else if (mode == 1) {
    if (wifiSuspendedForPower) {
      resumeWiFiFromPower();
    }
    wakeDisplayPanel();
    M5Dial.Display.setBrightness(settings::cfg.brightnessDim);
  } else {
    M5Dial.Display.setBrightness(0);
    sleepDisplayPanel();
  }
  applyWiFiPowerSave();
}

// Deep sleep stops LEDC and releases the backlight PWM pin, which lets the backlight come on over a
// sleeping (black) panel. Drive it low and latch it so it stays off until setup() releases it.
void holdBacklightOff() {
  const gpio_num_t bl = static_cast<gpio_num_t>(DISPLAY_BACKLIGHT_PIN);
  ledcDetach(bl);
  pinMode(bl, OUTPUT);
  digitalWrite(bl, LOW);
  gpio_hold_en(bl);
  gpio_deep_sleep_hold_en();
}

void powerOffDevice() {
  setStatus("Powering off");
  if (!SERIAL_OUTPUT_ONLY && wtClient.connected()) {
    if (locoAcquired || locoAcquirePending) {
      backendRelease();
      locoAcquired = false;
      locoAcquirePending = false;
    }
    backendQuit();
    wtClient.flush();
    delay(100);
    wtClient.stop();
  }
  if (!SERIAL_OUTPUT_ONLY) {
    WiFi.disconnect(true, true);
    WiFi.mode(WIFI_OFF);
  }
  M5Dial.Rfid.PCD_AntennaOff();
  Serial.println("Power off (battery: press dial button to restart; USB: touch screen to wake)");
  Serial.flush();
  M5Dial.Display.setBrightness(0);
  M5Dial.Display.sleep();
  M5Dial.Display.waitDisplay();
  holdBacklightOff();
  // On battery the hold circuit cuts power. On USB the ESP32 stays powered and M5Unified falls back to
  // deep sleep, so arm the touch controller INT line (GPIO14, RTC capable) as a wake source first.
  rtc_gpio_pullup_en(GPIO_NUM_14);
  rtc_gpio_pulldown_dis(GPIO_NUM_14);
  esp_sleep_enable_ext0_wakeup(GPIO_NUM_14, 0);
  M5Dial.Power.powerOff();
}

void updatePowerState() {
  const unsigned long idleMs = millis() - lastUserActivityMs;
  uint8_t target = 0;
  if (idleMs >= (settings::cfg.offAfterSec * 1000UL)) {
    target = 2;
  } else if (idleMs >= (settings::cfg.dimAfterSec * 1000UL)) {
    target = 1;
  }

  if (target != backlightMode) {
    enterBacklightMode(target);
  }

  // Only drop the WiThrottle link (and later sleep/power off) once the loco is stopped, so a train
  // running hands-off keeps receiving heartbeats.
  if (backlightMode == 2 && !wifiSuspendedForPower && throttleIsIdleSafe()) {
    suspendWiFiForPower();
  }

  if ((settings::cfg.powerOffAfterMin * 60000UL) > 0 && idleMs >= (settings::cfg.powerOffAfterMin * 60000UL) && throttleIsIdleSafe() &&
      !(POWER_OFF_ONLY_ON_BATTERY && onExternalPower())) {
    powerOffDevice();
  }
}

// Light-sleep between polls while the display is off and WiFi is already suspended.
void idleSleep() {
  // Light sleep drops the USB-JTAG-serial link, so skip it whenever a USB host is physically present
  // (SOF frames seen), not just while a terminal has the port open.
  if (!ENABLE_LIGHT_SLEEP_WHEN_DISPLAY_OFF || !wifiSuspendedForPower || M5Dial.Speaker.isPlaying() ||
      (LIGHT_SLEEP_SKIP_WHEN_USB_SERIAL && HWCDC::isPlugged())) {
    delay(LOOP_DELAY_OFF_MS);
    return;
  }

  Serial.flush();
  const gpio_num_t encA = static_cast<gpio_num_t>(DIAL_ENCODER_PIN_A);
  const gpio_num_t encB = static_cast<gpio_num_t>(DIAL_ENCODER_PIN_B);
  const gpio_num_t btn = GPIO_NUM_42;      // dial push button
  const gpio_num_t touchInt = GPIO_NUM_14; // FT3267 touch INT (active low)
  gpio_wakeup_enable(encA, gpio_get_level(encA) ? GPIO_INTR_LOW_LEVEL : GPIO_INTR_HIGH_LEVEL);
  gpio_wakeup_enable(encB, gpio_get_level(encB) ? GPIO_INTR_LOW_LEVEL : GPIO_INTR_HIGH_LEVEL);
  gpio_wakeup_enable(btn, GPIO_INTR_LOW_LEVEL);
  gpio_wakeup_enable(touchInt, GPIO_INTR_LOW_LEVEL);
  esp_sleep_enable_gpio_wakeup();
  esp_sleep_enable_timer_wakeup(static_cast<uint64_t>(LIGHT_SLEEP_INTERVAL_MS) * 1000ULL);
  esp_light_sleep_start();

  // gpio_wakeup_enable() re-types these pins as level interrupts. Restore the encoder library's edge
  // interrupts and leave the polled pins with interrupts disabled, or the ISR would run continuously.
  gpio_wakeup_disable(encA);
  gpio_wakeup_disable(encB);
  gpio_wakeup_disable(btn);
  gpio_wakeup_disable(touchInt);
  gpio_set_intr_type(encA, GPIO_INTR_ANYEDGE);
  gpio_set_intr_type(encB, GPIO_INTR_ANYEDGE);
  gpio_set_intr_type(btn, GPIO_INTR_DISABLE);
  gpio_set_intr_type(touchInt, GPIO_INTR_DISABLE);
  esp_sleep_disable_wakeup_source(ESP_SLEEP_WAKEUP_TIMER);
  esp_sleep_disable_wakeup_source(ESP_SLEEP_WAKEUP_GPIO);
}

// Piecewise 1S Li-ion/LiPo open-circuit voltage curve.
int batteryPercentFromMillivolts(int mv) {
  static const struct {
    int mv;
    int pct;
  } curve[] = {{4200, 100}, {4100, 92}, {4000, 80}, {3900, 65}, {3850, 55}, {3800, 45}, {3750, 35},
               {3700, 25},  {3650, 17}, {3600, 10}, {3500, 5},  {3400, 2},  {3300, 0}};
  const size_t n = sizeof(curve) / sizeof(curve[0]);
  if (mv >= curve[0].mv) {
    return 100;
  }
  if (mv <= curve[n - 1].mv) {
    return 0;
  }
  for (size_t i = 1; i < n; ++i) {
    if (mv >= curve[i].mv) {
      const int span = curve[i - 1].mv - curve[i].mv;
      return curve[i].pct + (curve[i - 1].pct - curve[i].pct) * (mv - curve[i].mv) / span;
    }
  }
  return 0;
}

bool onExternalPower() {
  return powerSource == PowerSource::External || chargeState == ChargeState::Charging;
}

void samplePowerSource(bool force) {
  const unsigned long now = millis();
  if (!force && (now - lastPowerSourceSampleMs) < 1000) {
    return;
  }
  lastPowerSourceSampleMs = now;

  // A USB host keeps sending SOF frames; a plain charger or the DC terminal does not, so this alone
  // can only prove "external", never "battery".
  usbHostPresent = HWCDC::isPlugged();
  PowerSource ps = usbHostPresent ? PowerSource::External : PowerSource::Unknown;
  if (POWER_SENSE_ADC_PIN >= 0) {
    uint32_t acc = 0;
    for (int i = 0; i < 8; ++i) {
      acc += analogReadMilliVolts(static_cast<uint8_t>(POWER_SENSE_ADC_PIN));
    }
    powerSenseMillivolts = static_cast<int>((acc / 8) * POWER_SENSE_DIVIDER_RATIO + 0.5f);
    ps = (usbHostPresent || powerSenseMillivolts >= POWER_SENSE_MIN_MV) ? PowerSource::External
                                                                         : PowerSource::Battery;
  }

  ChargeState cs = ChargeState::Unknown;
  if (CHARGE_STATUS_PIN >= 0) {
    const bool low = digitalRead(CHARGE_STATUS_PIN) == LOW;
    cs = (low == CHARGE_STATUS_ACTIVE_LOW) ? ChargeState::Charging : ChargeState::NotCharging;
  }

  if (ps != powerSource || cs != chargeState) {
    powerSource = ps;
    chargeState = cs;
    uiDirty = true;
  }
}

void sampleBattery(bool force) {
  const unsigned long now = millis();
  if (!force && (now - lastBatterySampleMs) < BATTERY_SAMPLE_INTERVAL_MS) {
    return;
  }
  lastBatterySampleMs = now;

  int mv = -1;
  int pct = -1;
  if (BATTERY_ADC_PIN >= 0) {
    uint32_t acc = 0;
    for (int i = 0; i < 16; ++i) {
      acc += analogReadMilliVolts(static_cast<uint8_t>(BATTERY_ADC_PIN));
    }
    mv = static_cast<int>((acc / 16) * BATTERY_DIVIDER_RATIO + 0.5f);
    if (batteryMillivolts > 0 && !force) {
      mv = (batteryMillivolts * 3 + mv) / 4; // light smoothing against load transients
    }
    pct = batteryPercentFromMillivolts(mv);
  } else {
    // The M5Dial has no battery sense line, so this returns -2 today; kept so a future M5Unified
    // release (or a different board) works without changes.
    const int32_t level = M5Dial.Power.getBatteryLevel();
    if (level >= 0 && level <= 100) {
      pct = static_cast<int>(level);
    }
  }

  batteryMillivolts = mv;
  if (pct != batteryPercent) {
    batteryPercent = pct;
    uiDirty = true;
  }
  if (pct >= 0 && pct <= BATTERY_LOW_WARN_PERCENT) {
    if (!batteryLowWarned) {
      batteryLowWarned = true;
      setStatus(String("Battery low: ") + pct + "%");
      beep();
    }
  } else if (pct > BATTERY_LOW_WARN_PERCENT + 5) {
    batteryLowWarned = false;
  }
}

int notchToSpeed(int notch) {
  if (notch < 0) {
    notch = 0;
  }
  if (notch > notchCount()) {
    notch = notchCount();
  }
  return (notch * 126 + notchCount() / 2) / notchCount();
}

int speedToNotch(int speed) {
  if (speed <= 0) {
    return 0;
  }
  if (speed >= 126) {
    return notchCount();
  }
  return (speed * notchCount() + 63) / 126;
}

void syncEncoderToSpeed() {
  const int32_t rawTarget = static_cast<int32_t>(throttleNotch) * settings::cfg.clicksPerNotch *
                            ENCODER_RAW_COUNTS_PER_STEP * encoderSign();
  M5Dial.Encoder.write(rawTarget);
  // Ignore one encoder delta after write() so we don't interpret the sync as user rotation.
  encoderResyncPending = true;
}

// Operator selects a notch; with momentum the speed follows over time, otherwise immediately.
void applyNotch(int notch, bool fromEncoder) {
  if (notch < 0) {
    notch = 0;
  } else if (notch > maxNotch()) {
    notch = maxNotch();
  }
  if (estopLatched && notch > 0) {
    setStatus("E-Stop latched: press BtnA to clear");
    if (!fromEncoder) {
      return;
    }
    notch = 0;
  }
  if (notch == throttleNotch && throttleDemandSpeed == notchToSpeed(notch)) {
    return;
  }
  throttleNotch = notch;
  throttleDemandSpeed = notchToSpeed(notch);
  uiDirty = true;
  if (!fromEncoder) {
    syncEncoderToSpeed();
  }
  if (notch > 0) {
    ensureLocoAcquired();
  }
  if (brakeHoldActive || brakeRecovering) {
    brakeRecoveryTargetSpeed = throttleDemandSpeed;
    return;
  }
  if (settings::cfg.momentum) {
    lastMomentumMs = millis();
    return;
  }
  encoderUpdatingSpeed = true;
  setSpeed(throttleDemandSpeed);
  encoderUpdatingSpeed = false;
}

// Ramp the actual speed toward the notch target.
void handleMomentum() {
  if (!settings::cfg.momentum || brakeHoldActive || brakeRecovering || estopLatched) {
    return;
  }
  const unsigned long now = millis();
  const int target = throttleDemandSpeed;
  if (speed126 == target) {
    lastMomentumMs = now;
    momentumAccumMilli = 0;
    return;
  }
  const unsigned long dt = now - lastMomentumMs;
  if (dt < MOMENTUM_TICK_MS) {
    return;
  }
  lastMomentumMs = now;
  const float rate = (speed126 < target) ? static_cast<float>(settings::cfg.accelPerSec) : static_cast<float>(settings::cfg.decelPerSec);
  momentumAccumMilli += static_cast<int32_t>(rate * 1000.0f * static_cast<float>(dt) / 1000.0f);
  const int steps = momentumAccumMilli / 1000;
  if (steps <= 0) {
    return;
  }
  momentumAccumMilli -= steps * 1000;
  int next = (speed126 < target) ? min(speed126 + steps, target) : max(speed126 - steps, target);
  encoderUpdatingSpeed = true;
  setSpeed(next);
  encoderUpdatingSpeed = false;
}

String buildLocoId(uint16_t address, bool isLong) {
  return String(isLong ? "L" : "S") + String(address);
}

void updateLocoLabel() {
  if (!locoSelected) {
    locoId = "-";
    return;
  }
  locoId = buildLocoId(activeLocoAddress, activeLocoIsLong);
}
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
void loop() {
  const uint32_t loopStartUsec = micros();
  M5Dial.update();
  updatePowerState();
  serviceWiFi();
  if (usingLcc() && !wifiSuspendedForPower) {
    lcc::service();
  }

  readSerialCommands();
  handleEncoder();
  handleTouchBrake();
  handleButton();
  handleKeypad();
  handleRfid();
  handleMomentum();
  readServer();
  serviceLocoAcquire();
  expireInfoLine();
  samplePowerSource(false);
  sampleBattery(false);

  if (!SERIAL_OUTPUT_ONLY && wtClient.connected() && (millis() - lastHeartbeatMs) > 2000) {
    sendWt("*");
    lastHeartbeatMs = millis();
  }

  if (!SERIAL_OUTPUT_ONLY && (millis() - lastServerActivityMs) > 15000 && wtClient.connected()) {
    setInfo("Waiting for server data");
  }

  if (uiDirty && backlightMode != 2) {
    drawUi();
  }
  if (backlightMode == 0) {
    delay(LOOP_DELAY_ACTIVE_MS);
  } else if (backlightMode == 1) {
    delay(LOOP_DELAY_DIM_MS);
  } else {
    idleSleep();
  }
  lastLoopUsec = micros() - loopStartUsec;
  if (lastLoopUsec > maxLoopUsec) {
    maxLoopUsec = lastLoopUsec;
  }
}

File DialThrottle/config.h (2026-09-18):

#pragma once

// WiFi settings
static const char* WIFI_SSID = "YOUR_WIFI_SSID";
static const char* WIFI_PASS = "YOUR_WIFI_PASSWORD";

// Throttle protocol: WiThrottle (JMRI, Engine Driver compatible) or LCC/OpenLCB over GridConnect.
#define PROTOCOL_WITHROTTLE 0
#define PROTOCOL_LCC_GRIDCONNECT 1
// Override at build time with: make build DEFINES=-DTHROTTLE_PROTOCOL_DEFAULT=PROTOCOL_LCC_GRIDCONNECT
#ifndef THROTTLE_PROTOCOL_DEFAULT
#define THROTTLE_PROTOCOL_DEFAULT PROTOCOL_WITHROTTLE
#endif
// This is only the default for a device with nothing saved yet; the settings screen wins after that.
static const uint8_t THROTTLE_PROTOCOL = THROTTLE_PROTOCOL_DEFAULT;

// JMRI WiThrottle server settings
static const char* WITHROTTLE_HOST = "192.168.1.50";
static const uint16_t WITHROTTLE_PORT = 12090;
// TCP connect timeout for the WiThrottle server. Connect attempts block the UI for at most this long;
// retries back off from 5 s to 30 s while the server is unreachable.
static const uint32_t WITHROTTLE_CONNECT_TIMEOUT_MS = 1500;

// Locomotive settings
static const uint16_t LOCO_ADDRESS = 3;
static const bool LOCO_IS_LONG_ADDRESS = false;

// Reverse is capped to this fraction of the notches, so the dial only reaches half speed backwards.
// 1 gives reverse the same range as forward.
static const uint8_t REVERSE_NOTCH_DIVISOR = 2;

// Device identity shown in JMRI
static const char* THROTTLE_NAME = "DialThrottle";
static const char* THROTTLE_ID_PREFIX = "M5DIAL-";

// The second status line clears after this long, which brings back the "Btn Hold = Setup" hint.
static const uint32_t INFO_LINE_TIMEOUT_MS = 8000;

// Hold the dial button this long to open the on-device settings screen (protocol, server address
// and port). Settings are saved in flash and survive a reflash of the firmware.
static const uint32_t SETTINGS_LONG_PRESS_MS = 1200;

// Multi-throttle key. Any single character identifies this throttle to the server; Engine Driver
// uses '0' to '6'.
static const char WITHROTTLE_THROTTLE_KEY = '0';
// JMRI echoes every speed command back. A report matching one we sent within this window is treated
// as our own echo rather than another throttle moving the loco.
static const uint32_t WITHROTTLE_ECHO_WINDOW_MS = 4000;
// When the server says the loco is already in use, take it automatically. Set false to require the
// serial 'steal' command instead, which is safer if someone else may be running that loco.
static const bool WITHROTTLE_AUTO_STEAL = true;
// How long to wait for the server to confirm an acquire before retrying.
static const uint32_t ACQUIRE_CONFIRM_TIMEOUT_MS = 3000;
static const uint8_t ACQUIRE_MAX_ATTEMPTS = 3;

// LCC / OpenLCB over a GridConnect TCP link (JMRI's LCC GridConnect server, or a CAN gateway).
// Only used when THROTTLE_PROTOCOL is PROTOCOL_LCC_GRIDCONNECT.
static const char* LCC_GRIDCONNECT_HOST = WITHROTTLE_HOST;
static const uint16_t LCC_GRIDCONNECT_PORT = 12021;
static const uint32_t LCC_CONNECT_TIMEOUT_MS = 1500;
// This node's LCC node ID. It must be unique on the network. The default keeps the top three bytes
// (05.01.01 is the range openlcb.org set aside for non-commercial use) and makes the low three bytes
// unique to this board from its MAC address. Set LCC_NODE_ID_FROM_MAC false to use the value as-is.
static const uint64_t LCC_NODE_ID = 0x050101011234ULL;
static const bool LCC_NODE_ID_FROM_MAC = true;
// Speed scaling. The traction protocol carries speed in metres per second, so the throttle's top
// notch has to be mapped to a prototype speed. 126 mph puts one speed step at one mph, which matches
// the usual OpenMRN command station mapping. Adjust if your command station scales differently.
static const float LCC_FULL_SPEED_MPH = 126.0f;
// Alias reservation window: the standard requires at least 200 ms between the CID frames and RID.
static const uint32_t LCC_ALIAS_RESERVE_WAIT_MS = 250;
static const uint32_t LCC_TRAIN_QUERY_TIMEOUT_MS = 1500;
static const uint8_t LCC_TRAIN_QUERY_ATTEMPTS = 4;
// LCC accessories are event driven, so turnout numbers are mapped onto an event range by convention:
// turnout n produces base + 2n (closed) or base + 2n + 1 (thrown).
static const uint64_t LCC_TURNOUT_EVENT_BASE = 0x0501010114FF0000ULL;

// Optional SparkFun Qwiic Keypad address (default is 0x4B)
static const uint8_t KEYPAD_I2C_ADDR = 0x4B;
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

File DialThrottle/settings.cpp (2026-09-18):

#include "settings.h"

#include <Preferences.h>
#include <string.h>

#include "config.h"

namespace settings {

Config cfg = {};

namespace {

constexpr uint8_t CONFIG_VERSION = 1;
constexpr size_t VISIBLE_ROWS = 5;

Preferences prefs;
ApplyFn applyCallback = nullptr;
bool opened = false;
bool storedLoaded = false;

enum class ItemType : uint8_t { Submenu, Bool, Int, Enum, Ip, Text, Info, Action, Back };
enum class Action : uint8_t { None, SaveExit, Exit, ResetDefaults };

struct Item {
  const char* label;
  ItemType type;
  void* value;       // uint8_t, uint16_t or char[] depending on type and width
  uint8_t width;     // bytes of the value, or buffer size for Text
  int32_t min;
  int32_t max;
  int32_t step;
  const char* const* choices;
  uint8_t choiceCount;
  uint8_t target;    // page index for Submenu
  Action action;
  bool masked;       // Text: show as dots
};

const char* const PROTOCOL_NAMES[] = {"WiThrottle", "LCC"};
const char* const OFF_ON[] = {"Off", "On"};
const char* const SHORT_LONG[] = {"Short", "Long"};

#define ITEM_SUB(label, page) {label, ItemType::Submenu, nullptr, 0, 0, 0, 0, nullptr, 0, page, Action::None, false}
#define ITEM_BOOL(label, field) \
  {label, ItemType::Bool, &cfg.field, sizeof(cfg.field), 0, 1, 1, OFF_ON, 2, 0, Action::None, false}
#define ITEM_INT(label, field, lo, hi, st) \
  {label, ItemType::Int, &cfg.field, sizeof(cfg.field), lo, hi, st, nullptr, 0, 0, Action::None, false}
#define ITEM_ENUM(label, field, names, count) \
  {label, ItemType::Enum, &cfg.field, sizeof(cfg.field), 0, (count)-1, 1, names, count, 0, Action::None, false}
#define ITEM_IP(label) {label, ItemType::Ip, cfg.ip, 4, 0, 255, 1, nullptr, 0, 0, Action::None, false}
#define ITEM_TEXT(label, field, mask) \
  {label, ItemType::Text, cfg.field, sizeof(cfg.field), 0, 0, 0, nullptr, 0, 0, Action::None, mask}
#define ITEM_ACTION(label, act) {label, ItemType::Action, nullptr, 0, 0, 0, 0, nullptr, 0, 0, act, false}
#define ITEM_BACK() {"Back", ItemType::Back, nullptr, 0, 0, 0, 0, nullptr, 0, 0, Action::None, false}
#define ITEM_INFO(label) {label, ItemType::Info, nullptr, 0, 0, 0, 0, nullptr, 0, 0, Action::None, false}

enum PageId : uint8_t { PAGE_ROOT = 0, PAGE_NETWORK, PAGE_THROTTLE, PAGE_DISPLAY, PAGE_SYSTEM, PAGE_COUNT };

const Item ROOT_ITEMS[] = {
    ITEM_SUB("Network", PAGE_NETWORK),
    ITEM_SUB("Throttle", PAGE_THROTTLE),
    ITEM_SUB("Display & power", PAGE_DISPLAY),
    ITEM_SUB("System", PAGE_SYSTEM),
    ITEM_ACTION("Save & exit", Action::SaveExit),
    ITEM_ACTION("Discard & exit", Action::Exit),
};

const Item NETWORK_ITEMS[] = {
    ITEM_TEXT("WiFi name", ssid, false),
    ITEM_TEXT("WiFi pass", pass, true),
    ITEM_ENUM("Protocol", protocol, PROTOCOL_NAMES, 2),
    ITEM_IP("Server"),
    ITEM_INT("Port", port, 1, 65535, 1),
    ITEM_BACK(),
};

const Item THROTTLE_ITEMS[] = {
    ITEM_INT("Loco addr", locoAddress, 1, 9999, 1),
    ITEM_ENUM("Addr type", locoIsLong, SHORT_LONG, 2),
    ITEM_INT("Notches", notchCount, 4, 16, 4), // 4, 8, 12 or 16
    ITEM_INT("Clicks/notch", clicksPerNotch, 1, 4, 1),
    ITEM_BOOL("Reverse dial", encoderReversed),
    ITEM_BOOL("Momentum", momentum),
    ITEM_INT("Accel /s", accelPerSec, 1, 60, 1),
    ITEM_INT("Decel /s", decelPerSec, 1, 60, 1),
    ITEM_BACK(),
};

const Item DISPLAY_ITEMS[] = {
    ITEM_INT("Brightness", brightnessActive, 10, 255, 5),
    ITEM_INT("Dim level", brightnessDim, 0, 120, 2),
    ITEM_INT("Dim after s", dimAfterSec, 2, 600, 2),
    ITEM_INT("Off after s", offAfterSec, 5, 900, 5),
    ITEM_INT("Power off min", powerOffAfterMin, 0, 240, 1),
    ITEM_BOOL("Sound", sound),
    ITEM_BACK(),
};

const Item SYSTEM_ITEMS[] = {
    ITEM_BOOL("RFID reader", rfidEnabled),
    ITEM_ACTION("Reset defaults", Action::ResetDefaults),
    ITEM_BACK(),
};

struct Page {
  const char* title;
  const Item* items;
  uint8_t count;
};

const Page PAGES[PAGE_COUNT] = {
    {"SETTINGS", ROOT_ITEMS, sizeof(ROOT_ITEMS) / sizeof(Item)},
    {"NETWORK", NETWORK_ITEMS, sizeof(NETWORK_ITEMS) / sizeof(Item)},
    {"THROTTLE", THROTTLE_ITEMS, sizeof(THROTTLE_ITEMS) / sizeof(Item)},
    {"DISPLAY", DISPLAY_ITEMS, sizeof(DISPLAY_ITEMS) / sizeof(Item)},
    {"SYSTEM", SYSTEM_ITEMS, sizeof(SYSTEM_ITEMS) / sizeof(Item)},
};

uint8_t page = PAGE_ROOT;
uint8_t sel = 0;
uint8_t scrollTop = 0;
uint8_t pageStack[4] = {};
uint8_t selStack[4] = {};
uint8_t stackDepth = 0;

// Editing state.
enum class Edit : uint8_t { None, Value, Ip, Text };
Edit edit = Edit::None;
int8_t ipOctet = 0;
bool digitFresh = true;

// Text editor state.
const char TEXT_CHARS[] =
    "abcdefghijklmnopqrstuvwxyzABCDEFGHIJKLMNOPQRSTUVWXYZ0123456789 -_.:/@#!$%&*+=?,()[]";
constexpr uint8_t TEXT_EXTRA = 2; // 0 = done, 1 = backspace
int16_t textPick = TEXT_EXTRA;
char textBuf[65] = {};
uint8_t textLimit = 0;
char* textTarget = nullptr;

const Item& currentItem() {
  return PAGES[page].items[sel];
}
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

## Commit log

2026-09-18 Add docs and switch to Arduino
    [M5DialController-Backplate.stl, M5DialController-Body.stl, M5DialController.FCStd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]
2026-09-22 docs: put the product shot on the home page
    The overview page opened with nothing but type. Add the render of the
    assembled throttle - Dial, keypad and printed case - and give the hero a
    second column for it on wide viewports, with the spec cards squaring up
    to 2x2 alongside. Below 1000px the shot drops under the cards and caps
    at 320px so it never dominates a narrow column.
    The render carries its own light studio backdrop, so it fills its card
    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
2026-09-22 docs: swap the home page shot for the transparent render
    The render now has an alpha channel, so the device floats straight on the
    page instead of sitting on a light studio plate in a card. Drop the card
    and crop in CSS: a portrait window at the device's own bounds within the
    square canvas, 870x1782 of 2048, with object-fit: cover. The device is
    centred in that canvas, so the crop needs no object-position, and the
    figure is sized by height since the device is tall and narrow.
    Strip the cast shadow from the asset while replacing it. Black at 40%, it
    was invisible against this background everywhere except the crop edge,
    where it left a hard-edged band beside the tapered base of the case.
    Co-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
2026-09-22 docs: take the shadowless render for the home page shot
    Replaces the version whose cast shadow had to be stripped here. The
    device sits in the same place on the same canvas, 870x1782 of 2048 and
    centred, so the CSS crop is untouched - only the note about removing the
    shadow goes, since there is no longer one to remove.
    Claude-Session: https://claude.ai/code/session_01A9uLCjmvySs7FKxPQa67AP
